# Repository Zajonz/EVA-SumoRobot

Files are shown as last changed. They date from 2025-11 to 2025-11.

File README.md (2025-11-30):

### EVA-SumoRobot

## ⚡ Overview
```
This robot is based on:

- 🧠 ESP32-S3 WROOM – main controller

- ⚙️ Pololu 37D motors – powerful drive system

- 🔌 2× Cytron MD13S – motor drivers

- 👀 2× E18-D80NK IR sensors – front detection

- 🔋 Designed for efficiency, stability and quick reaction times

# Current achievements:

- 🏆 Reached group stage twice in competitions

- (More soon as upgrades roll out)
```

## 🛠️ Current Features
```
- Fast dual-motor drive system

- Basic attack/escape behaviour logic

- Real-time sensor-based decision making

- Clean modular firmware on ESP32-S3

- Simple sensor calibration

- Future-proof structure for upgrades
```

## 🚀 Planned Upgrades (Next Versions)
```
- I’m actively upgrading the entire platform:
```

# 🔧 Electronics
```
- Full SMD PCB redesign

- Adding VL53L1X ToF sensors for precise distance measurement

- Using ATtiny402 to convert ToF readings into clean digital signals

- Custom H-bridge motor drivers for higher efficiency

- Better power distribution & noise handling
```

# 🧠 Software
```
- ⚙️ PID-based motion control

- Advanced strategy layers (angle attack, zone control, adaptive behavior)

- Real-time monitoring & debugging support
```

## 🧩 Components Used
```
- ESP32-S3 WROOM

- Pololu 37D 12V motors

- Cytron MD13S motor drivers

- E18-D80NK IR sensors

- Custom 3D-printed & machined parts
```

## 📚 Tech Stack
```
- Firmware: C++ / Arduino framework on PlatformIO

- Electronics: KiCad (upcoming SMD board)

- Mechanical design: Autodesk Fusion 360
```

## 🧪 Future Experiments
```
- Faster motor ramping

- Anti-spin logic

- Multi-sensor fusion

- Opponent tracking with ToF array

- Low-latency mode for ESP32-S3
```

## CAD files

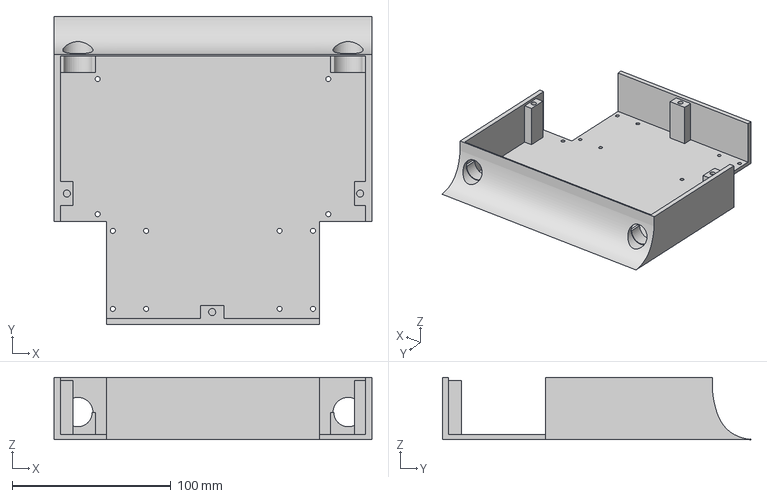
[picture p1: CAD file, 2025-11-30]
EvaFrame3DPrint.3mf
200.0 x 194.0 x 39.0 mm

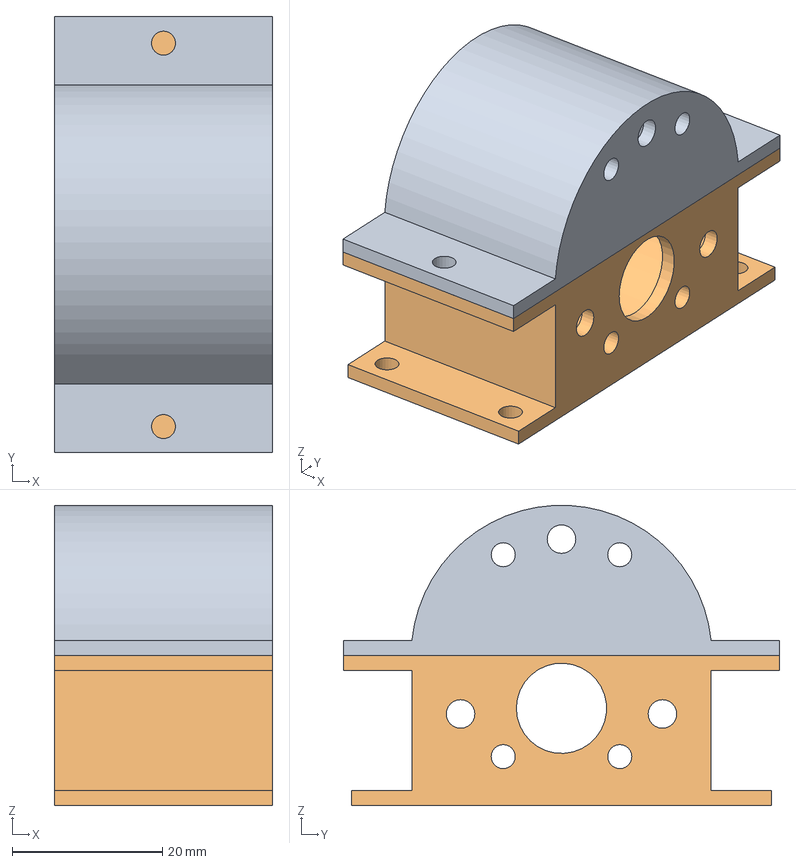
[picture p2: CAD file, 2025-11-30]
37D-Motor-Mount.3mf
29.0 x 58.0 x 39.9 mm
Bryła16
Bryła19

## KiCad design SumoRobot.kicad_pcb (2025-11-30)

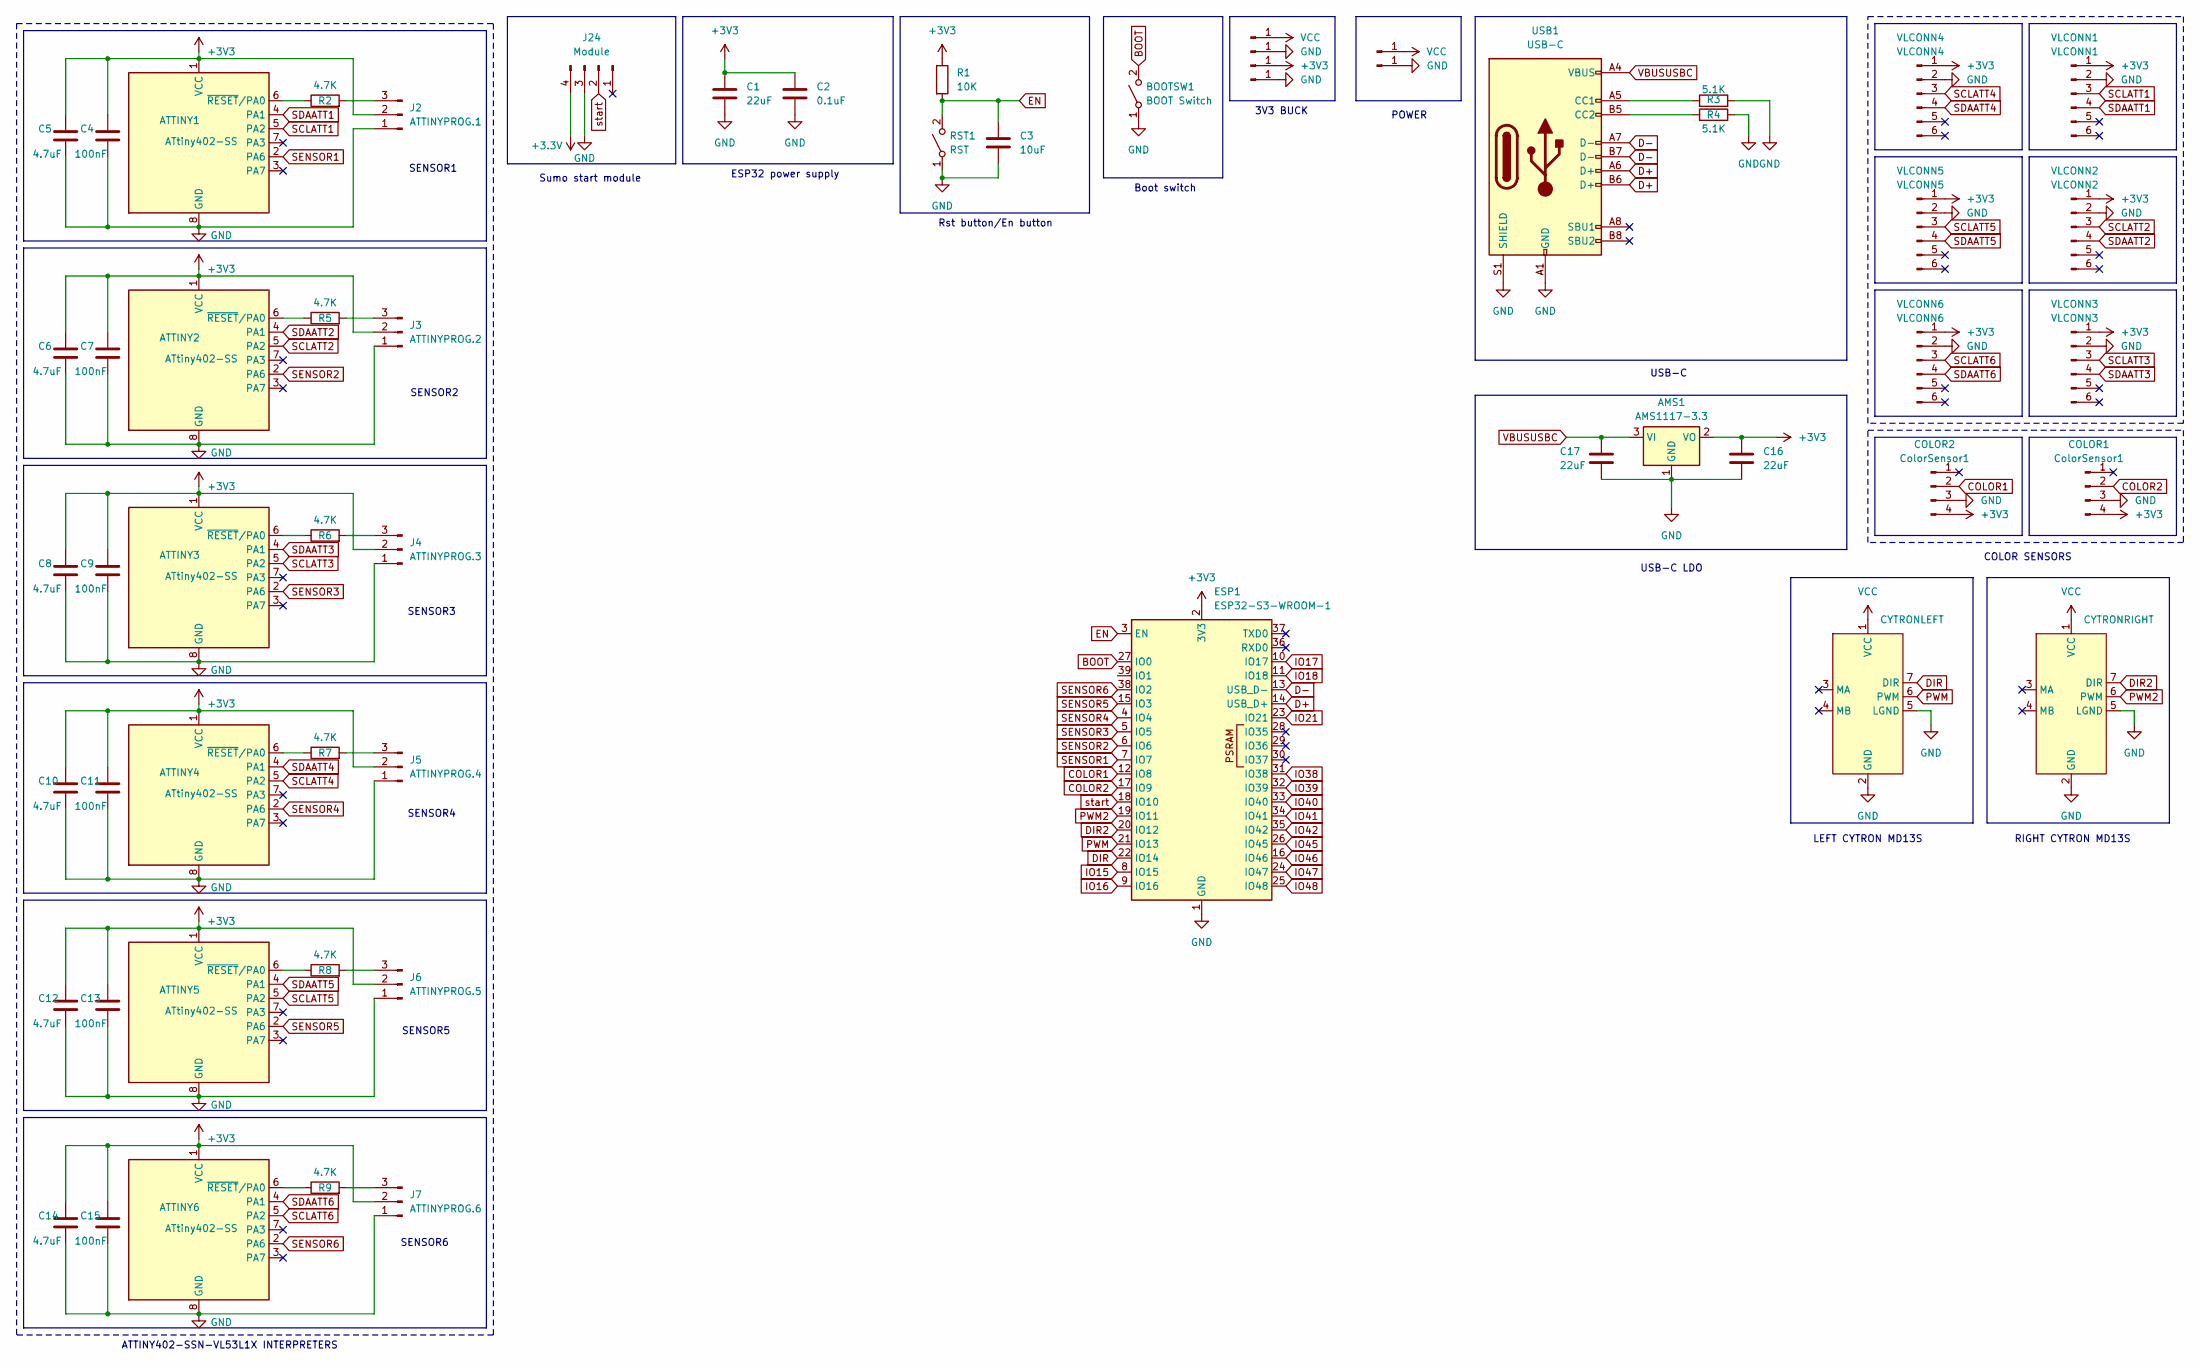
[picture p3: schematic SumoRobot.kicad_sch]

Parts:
3V3: 3V3; PinHeader_1x01_P2.54mm_Vertical
AMS1: AMS1117-3.3; SOT-223-3_TabPin2
ATTINY1, ATTINY2, ATTINY3, ATTINY4, ATTINY5, ATTINY6: ATtiny402-SS; SOIC-8_3.9x4.9mm_P1.27mm
BOOTSW1: BOOT Switch; SW_SPST_FSMSM
C1, C16, C17: 22uF; C_0805_2012Metric
C2: 0.1uF; C_0805_2012Metric
C3: 10uF; C_0805_2012Metric
C4, C7, C9, C11, C13, C15: 100nF; C_0805_2012Metric
C5, C6, C8, C10, C12, C14: 4.7uF; C_0805_2012Metric
COLOR1, COLOR2: ColorSensor1; JST_EH_B4B-EH-A_1x04_P2.50mm_Vertical
ESP1: ESP32-S3-WROOM-1; ESP32-S3-WROOM-1U
GND1: 3V3; SolderWirePad_1x01_SMD_5x10mm
J2: ATTINYPROG.1; JST_EH_B3B-EH-A_1x03_P2.50mm_Vertical
J3: ATTINYPROG.2; JST_EH_B3B-EH-A_1x03_P2.50mm_Vertical
J4: ATTINYPROG.3; JST_EH_B3B-EH-A_1x03_P2.50mm_Vertical
J5: ATTINYPROG.4; JST_EH_B3B-EH-A_1x03_P2.50mm_Vertical
J6: ATTINYPROG.5; JST_EH_B3B-EH-A_1x03_P2.50mm_Vertical
J7: ATTINYPROG.6; JST_EH_B3B-EH-A_1x03_P2.50mm_Vertical
J15, J17: 3V3; PinHeader_1x01_P2.54mm_Vertical
J24: Module; PinHeader_1x04_P2.54mm_Vertical
Left-Cytron1: CYTRONRIGHT; MD13S-Poprawione
R1: 10K; R_0805_2012Metric
R2, R5, R6, R7, R8, R9: 4.7K; R_0805_2012Metric
R3, R4: 5.1K; R_0805_2012Metric
RST1: RST; SW_SPST_FSMSM
Right-Cytron1: CYTRONLEFT; MD13S-Poprawione
USB1: USB-C; USB_C_Receptacle_GCT_USB4105-xx-A_16P_TopMnt_Horizontal
VCC1: 3V3; PinHeader_1x01_P2.54mm_Vertical
VCC2: 3V3; SolderWirePad_1x01_SMD_5x10mm
VLCONN1: VLCONN1; JST_EH_B6B-EH-A_1x06_P2.50mm_Vertical
VLCONN2: VLCONN2; JST_EH_B6B-EH-A_1x06_P2.50mm_Vertical
VLCONN3: VLCONN3; JST_EH_B6B-EH-A_1x06_P2.50mm_Vertical
VLCONN4: VLCONN4; JST_EH_B6B-EH-A_1x06_P2.50mm_Vertical
VLCONN5: VLCONN5; JST_EH_B6B-EH-A_1x06_P2.50mm_Vertical
VLCONN6: VLCONN6; JST_EH_B6B-EH-A_1x06_P2.50mm_Vertical

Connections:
+3.3V: J24.4
+3V3: 3V3.1, AMS1.2 (VO), ATTINY1.1 (VCC), ATTINY2.1 (VCC), ATTINY3.1 (VCC), ATTINY4.1 (VCC), ATTINY5.1 (VCC), ATTINY6.1 (VCC), C1.1, C2.1, C4.1, C5.1, C6.1, C7.1, C8.1, C9.1, C10.1, C11.1, C12.1, C13.1, C14.1, C15.1, C16.1, COLOR1.4, COLOR2.4, ESP1.2 (3V3), J2.2, J3.2, J4.2, J5.2, J6.2, J7.2, R1.1, VLCONN1.1, VLCONN2.1, VLCONN3.1, VLCONN4.1, VLCONN5.1, VLCONN6.1
BOOT: BOOTSW1.2 (B), ESP1.27 (IO0)
COLOR1: COLOR2.2, ESP1.12 (IO8)
COLOR2: COLOR1.2, ESP1.17 (IO9)
D+: ESP1.14 (USB_D+), USB1.A6 (D+), USB1.B6 (D+)
D-: ESP1.13 (USB_D-), USB1.A7 (D-), USB1.B7 (D-)
DIR: ESP1.22 (IO14), Right-Cytron1.7 (DIR)
DIR2: ESP1.20 (IO12), Left-Cytron1.7 (DIR)
EN: C3.1, ESP1.3 (EN), R1.2, RST1.2 (B)
GND: AMS1.1 (GND), ATTINY1.8 (GND), ATTINY2.8 (GND), ATTINY3.8 (GND), ATTINY4.8 (GND), ATTINY5.8 (GND), ATTINY6.8 (GND), BOOTSW1.1 (A), C1.2, C2.2, C3.2, C4.2, C5.2, C6.2, C7.2, C8.2, C9.2, C10.2, C11.2, C12.2, C13.2, C14.2, C15.2, C16.2, C17.2, COLOR1.3, COLOR2.3, ESP1.1 (GND), ESP1.40 (GND), ESP1.41 (GND), GND1.1, J2.1, J3.1, J4.1, J5.1, J6.1, J7.1, J15.1, J17.1, J24.3, Left-Cytron1.2 (GND), Left-Cytron1.5 (LGND), R3.2, R4.2, RST1.1 (A), Right-Cytron1.2 (GND), Right-Cytron1.5 (LGND), USB1.A1 (GND), USB1.A12 (GND), USB1.B1 (GND), USB1.B12 (GND), USB1.S1 (SHIELD), VLCONN1.2, VLCONN2.2, VLCONN3.2, VLCONN4.2, VLCONN5.2, VLCONN6.2
IO15: ESP1.8 (IO15)
IO16: ESP1.9 (IO16)
IO17: ESP1.10 (IO17)
IO18: ESP1.11 (IO18)
IO21: ESP1.23 (IO21)
IO38: ESP1.31 (IO38)
IO39: ESP1.32 (IO39)
IO40: ESP1.33 (IO40)
IO41: ESP1.34 (IO41)
IO42: ESP1.35 (IO42)
IO45: ESP1.26 (IO45)
IO46: ESP1.16 (IO46)
IO47: ESP1.24 (IO47)
IO48: ESP1.25 (IO48)
unnamed: ATTINY1.6 (~RESET/PA0), R2.1
unnamed: ATTINY2.6 (~RESET/PA0), R5.1
unnamed: ATTINY3.6 (~RESET/PA0), R6.1
unnamed: ATTINY4.6 (~RESET/PA0), R7.1
unnamed: ATTINY5.6 (~RESET/PA0), R8.1
unnamed: ATTINY6.6 (~RESET/PA0), R9.1
unnamed: J2.3, R2.2
unnamed: J3.3, R5.2
unnamed: J4.3, R6.2
unnamed: J5.3, R7.2
unnamed: J6.3, R8.2
unnamed: J7.3, R9.2
unnamed: R3.1, USB1.A5 (CC1)
unnamed: R4.1, USB1.B5 (CC2)
PWM: ESP1.21 (IO13), Right-Cytron1.6 (PWM)
PWM2: ESP1.19 (IO11), Left-Cytron1.6 (PWM)
SCLATT1: ATTINY1.5 (PA2), VLCONN1.3
SCLATT2: ATTINY2.5 (PA2), VLCONN2.3
SCLATT3: ATTINY3.5 (PA2), VLCONN3.3
SCLATT4: ATTINY4.5 (PA2), VLCONN4.3
SCLATT5: ATTINY5.5 (PA2), VLCONN5.3
SCLATT6: ATTINY6.5 (PA2), VLCONN6.3
SDAATT1: ATTINY1.4 (PA1), VLCONN1.4
SDAATT2: ATTINY2.4 (PA1), VLCONN2.4
SDAATT3: ATTINY3.4 (PA1), VLCONN3.4
SDAATT4: ATTINY4.4 (PA1), VLCONN4.4
SDAATT5: ATTINY5.4 (PA1), VLCONN5.4
SDAATT6: ATTINY6.4 (PA1), VLCONN6.4
SENSOR1: ATTINY1.2 (PA6), ESP1.7 (IO7)
SENSOR2: ATTINY2.2 (PA6), ESP1.6 (IO6)
SENSOR3: ATTINY3.2 (PA6), ESP1.5 (IO5)
SENSOR4: ATTINY4.2 (PA6), ESP1.4 (IO4)
SENSOR5: ATTINY5.2 (PA6), ESP1.15 (IO3)
SENSOR6: ATTINY6.2 (PA6), ESP1.38 (IO2)
VBUSUSBC: AMS1.3 (VI), C17.1, USB1.A4 (VBUS), USB1.A9 (VBUS), USB1.B4 (VBUS), USB1.B9 (VBUS)
VCC: Left-Cytron1.1 (VCC), Right-Cytron1.1 (VCC), VCC1.1, VCC2.1
start: ESP1.18 (IO10), J24.2

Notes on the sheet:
ESP32 power supply
POWER
3V3 BUCK
Rst button/En button
USB-C LDO
Sumo start module
SENSOR5
USB-C
SENSOR4
RIGHT CYTRON MD13S
Boot switch
LEFT CYTRON MD13S
SENSOR1
COLOR SENSORS
ATTINY402-SSN-VL53L1X INTERPRETERS
SENSOR2
SENSOR6
SENSOR3

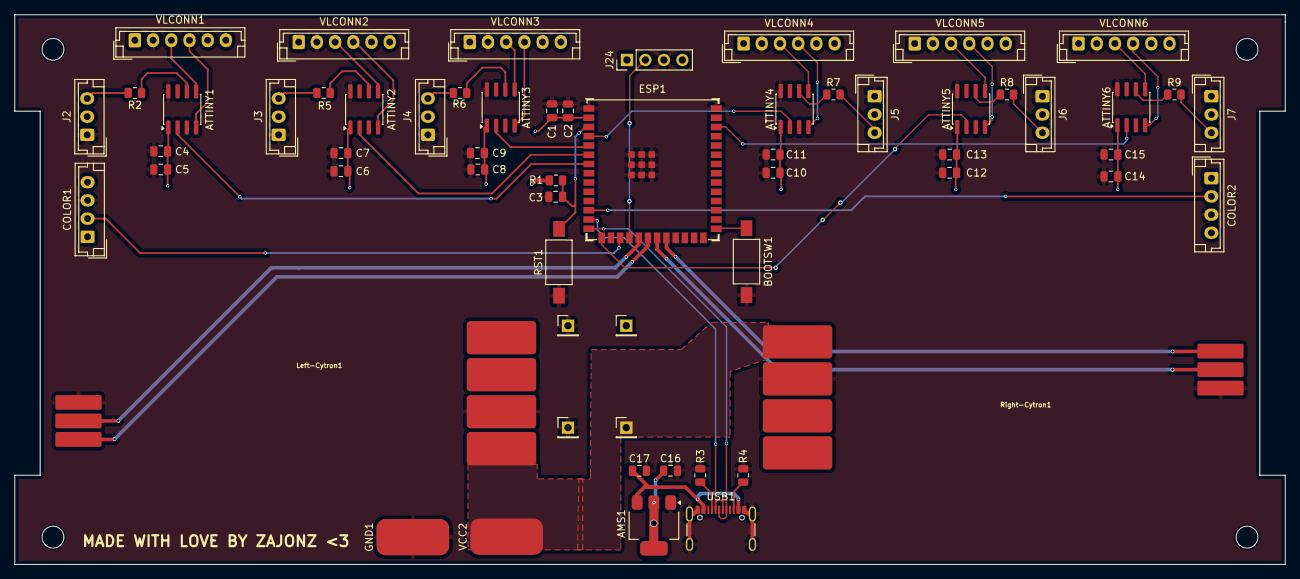
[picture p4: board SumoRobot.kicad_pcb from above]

Board: 2 copper layers, 174.5 x 75.5 mm, 60 parts (0 on the bottom side), 47 nets.
